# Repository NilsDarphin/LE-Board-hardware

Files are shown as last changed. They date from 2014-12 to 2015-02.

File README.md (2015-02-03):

#LE-Board-hardware

## The LEB Project

LEB is a college project which purpose is to allow you to control remotely the I/Os of a microcontroller.
The project consists of a Bluetooth low energy shield, its firmware, and an Android application.

**LEB works with the following projects :**

Repository  | Description
------------- | -------------
NilsDarphin/LEBoard_hardware      |Schematics and design of the board (Eagle files)
NilsDarphin/LEBoard_firmware      |Firmware of the board
NilsDarphin/LEB_Android           |Example of Android application

### Exemples of use

[Control the IOs from your Android](http://www.youtube.com/watch?v=B23XFl-bA60)

[Control a Car/Robot from your Android](http://www.youtube.com/watch?v=EagJ7pZ6EUM)

### What is it used for ?

The LEB Project allows you to develop easily Bluetooth low energy peripherals : 
Plug a LEB shield on your circuit and develop your own IOS or Android application.
You don't need to program the shield, everything is managed by the client (Smartphone, computer or smart home box...), so you have little electronic to do and no C/C++.

## The LEB Hardware

This repository contains the shield and the design of the LEB shield. You will need Eagle 6.0+ to open the files.

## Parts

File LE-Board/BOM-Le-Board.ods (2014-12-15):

Qty | Value | Device | Package | Parts | Description | Manufacturer PN
1 |  | DIODE-DO214AA | DO214AA | D2 | DIODE | CD214A-B120LF
1 |  | MA04-1 | MA04-1 | SV3 | PIN HEADER | 68002-404HLF
2 |  | MA08-1 | MA08-1 | SV1, SV2 | PIN HEADER | 68001-408HLF
1 | 100nF | C-EUC0603 | C0603 | C1 | CAPACITOR, European symbol | C0603C104K4RACTU
1 | 10k | R-US_R0603 | R0603 | R1 | RESISTOR, American symbol | CRCW060310K0FKEA
1 | 10uF | C-EUC0603 | C0603 | C2 | CAPACITOR, European symbol | C1608X5R0J106M080AB
1 | 10uF | C-USC0603 | C0603 | C3 | CAPACITOR, American symbol | C1608X5R0J106M080AB
1 | 309K | R-US_R0603 | R0603 | R2 | RESISTOR, American symbol | CRCW0603309KFKEA
1 | 4.7uF | C-USC0603 | C0603 | C4 | CAPACITOR, American symbol | C1608X5R0J475M080AB
1 | 4.7uH | L-USL2825P | L2825P | L1 | INDUCTOR, American symbol | 744029004
1 | 536K | R-US_R0603 | R0603 | R3 | RESISTOR, American symbol | ERJ-3EKF5363V
1 | BCM20732S | BCM20732S | LGA-48 | U$1 |  | BCM20732S
1 | CR2032_HLD | CR2032_HLD | CR2031_BAT_HLD | U$17 |  | BAT-HLD-001
1 | ELEVATOR | ELEVATOR | ELEVATOR | U$5 |  | MCP1640T-I/CHY
1 | FSM4JSMA | FSM4JSMA | FSM4JSMA | U$10 |  | PTS645SL43SMTR 92 LFS

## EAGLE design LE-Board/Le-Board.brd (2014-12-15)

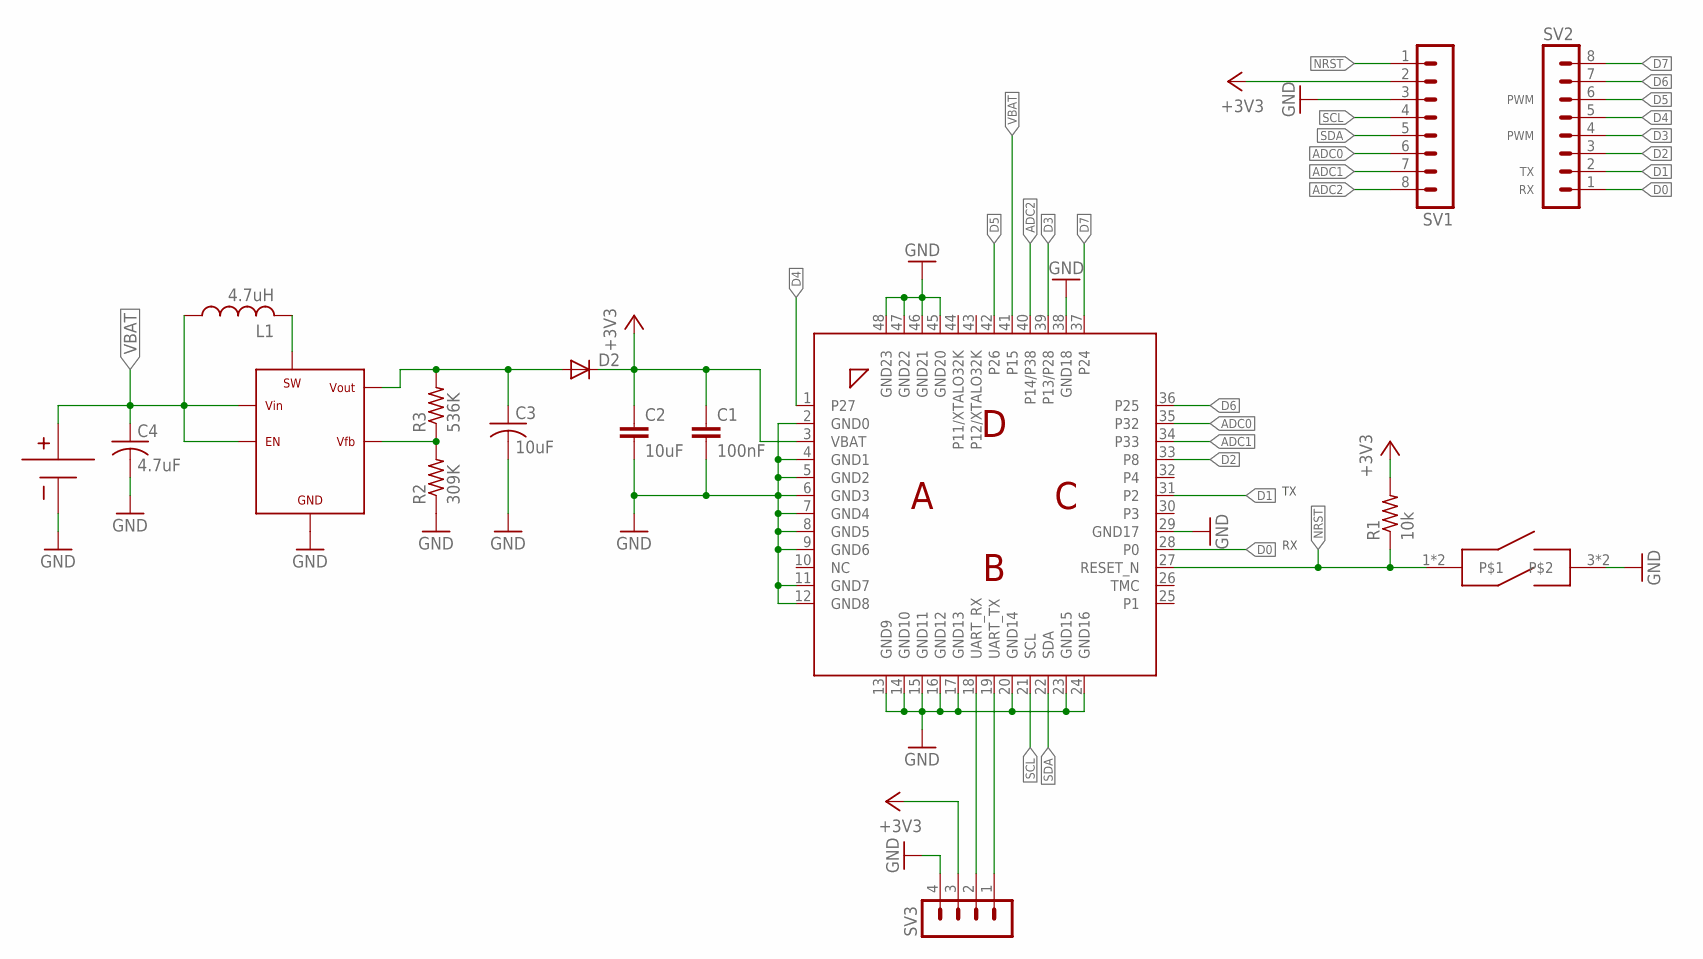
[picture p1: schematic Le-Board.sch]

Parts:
C1: 100nF; C0603
C2, C3: 10uF; C0603
C4: 4.7uF; C0603
D2: DIODE-DO214AA; DO214AA
L1: 4.7uH; L2825P
R1: 10k; R0603
R2: 309K; R0603
R3: 536K; R0603
SV1, SV2: MA08-1
SV3: MA04-1
U$1: BCM20732S; LGA-48
U$5: ELEVATOR
U$10: FSM4JSMA
U$17: CR2032_HLD; CR2031_BAT_HLD

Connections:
+3V3: C1.1, C2.1, D2.C, R1.2, SV1.2, SV3.3, U$1.3 (VBAT)
ADC0: SV1.6, U$1.35 (P32)
ADC1: SV1.7, U$1.34 (P33)
ADC2: SV1.8, U$1.40 (P14/P38)
D0: SV2.1, U$1.28 (P0)
D1: SV2.2, U$1.31 (P2)
D2: SV2.3, U$1.33 (P8)
D3: SV2.4, U$1.39 (P13/P28)
D4: SV2.5, U$1.1 (P27)
D5: SV2.6, U$1.42 (P26)
D6: SV2.7, U$1.36 (P25)
D7: SV2.8, U$1.37 (P24)
GND: C1.2, C2.2, C3.2, C4.2, R2.1, SV1.3, SV3.4, U$1.2 (GND0), U$1.4 (GND1), U$1.5 (GND2), U$1.6 (GND3), U$1.7 (GND4), U$1.8 (GND5), U$1.9 (GND6), U$1.11 (GND7), U$1.12 (GND8), U$1.13 (GND9), U$1.14 (GND10), U$1.15 (GND11), U$1.16 (GND12), U$1.17 (GND13), U$1.20 (GND14), U$1.23 (GND15), U$1.24 (GND16), U$1.29 (GND17), U$1.38 (GND18), U$1.45 (GND20), U$1.46 (GND21), U$1.47 (GND22), U$1.48 (GND23), U$5.2 (GND), U$10.3, U$10.4, U$17.BOT (-)
HCI_RX: SV3.2, U$1.18 (UART_RX)
HCI_TX: SV3.1, U$1.19 (UART_TX)
unnamed: C3.1, D2.A, R3.2, U$5.5 (VOUT)
unnamed: R2.2, R3.1, U$5.4 (VFB)
unnamed: L1.2, U$5.1 (SW)
NRST: R1.1, SV1.1, U$1.27 (RESET_N), U$10.1, U$10.2
SCL: SV1.4, U$1.21 (SCL)
SDA: SV1.5, U$1.22 (SDA)
VBAT: C4.1, L1.1, U$1.41 (P15), U$5.3 (EN), U$5.6 (VIN), U$17.TOP1 (+), U$17.TOP2 (+)

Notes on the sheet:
PWM

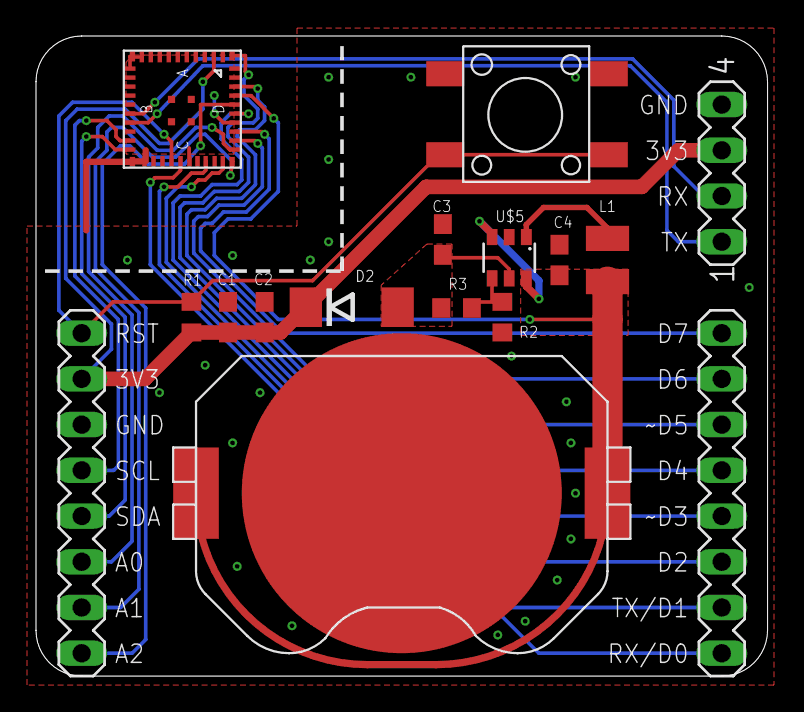
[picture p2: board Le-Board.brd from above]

Board: 2 copper layers, 40.6 x 35.6 mm, 16 parts (0 on the bottom side), 22 nets.

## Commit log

2014-12-15 LE Board v1.0
    [Le-Board.brd, Le-Board.sch]
2014-12-15 Added BOM
    [BOM-Le-Board.ods]
